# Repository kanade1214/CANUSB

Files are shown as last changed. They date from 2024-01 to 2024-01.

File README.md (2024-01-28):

# CANUSB 

created by kanade @kanade___1214

CAN通信とUSBのブリッジ基板です。  
高専ロボコン2023用に作成したものを配布用に安価に、誰でも使えるようにしました。  
作成、使用は自由ですが、kanadeに一声DMしていただけると喜びます。つながりを増やしたいので  

2024/1/28現在テスト期間につきプログラムの動作確認ができていない状況です。  
テスト期間が終わるまで少々お待ちください。  
代わりにPCでmidiを再生するとCANのパケットにするプログラムを入れてあります。

プログラムを書き込む前にプログラムの中にあるUSBのPIDをご自身のものに書き換えてください。  
~そのままで動く！わからない人はそのままで！~  

ROS2パッケージの説明を下に記述します。
(ROS2協力：@Pine_Pino_Pine)

# ROS2 can_communication

文責：Pine

## 前提

- ROS 2 Humble と Ubuntu 22.04 で動作確認済み
- Pythonライブラリpyserialを使用
    
    ```bash
    $ pip install pyserial
    ```
    
- カスタムメッセージ`CanMsg.msg`を使用
    
    ```cpp
    bool channel
    bool frametype
    uint32 id
    byte dlc
    byte[<=8] data
    ```
    
- kanade設計のCAN-USB基板を使用

## トピック

### publish

USB-CAN基板から受け取ったCANパケットをCanMsg型topic`/can_rx`としてpublishする

### subscribe

subscribeしたCanMsg型topic`/can_tx`をUSB-CAN基板にserialとして流す

## 通信仕様

### Serial

|  | 1 byte目 | 2 byte目 | 3 byte目 | 4~6 byte目 | 7 byte目 | 8~15 byte目 | 最後 |
| --- | --- | --- | --- | --- | --- | --- | --- |
| 目的 | メッセージ開始 | チャンネル | フレームタイプ | ID | DLC | データ | メッセージ終了 |
| 形式 | 0x02 | ASCIIコード | ASCIIコード | ASCIIコード | ASCIIコード |  | 0x03 |
| 備考 | tx時のみ　rxでは無し | ‘0’ or ‘1’ | ‘0’ or ‘1’ | 16進数 3桁 | ’1’ ~ ‘8’ | DLCに対応した長さ | tx時のみ　rxでは無し |

フレームタイプが1（リモートフレーム）のときはDLCに関わらずdataは無効（rx時は無視され、tx時は空）

### CanMsg

|  | 目的 | 型 (ROS) | 型 (Python) | 型 (C++) | 形式 |
| --- | --- | --- | --- | --- | --- |
| channel | 使用するCAN Busのチャンネル | bool | bool | bool | false: ch0　true: ch1 |
| frametype | データフレームとリモートフレームの選択 | bool | bool | bool | false: データフレーム　true: リモートフレーム |
| id | CANデバイスのID | uint32 | int | uint32_t | 非負整数（例：0x201なら513） |
| dlc | データのbyte長 | byte | bytes | uint8_t | ASCIIコード 1文字 |
| data | データ | byte配列 | bytesリスト | uint8_t配列 | 各デバイスの仕様による |

## Pythonでの使用例

### TX

```python
import rclpy
from rclpy.node import Node
from custom_messages.msg import CanMsg

class publisher(Node) :
    def __init__(self) :
        super().__init__('publisher')
        
        self.pub = self.create_publisher(CanMsg, '/can_tx', 1)
        
        # 1秒周期で整数値とテキストを送信させる
        self.create_timer(1, self.publish_integer)
        self.create_timer(1, self.publish_text)
    
    def publish_integer(self) :
        # 送信する数値（符号なし8bit整数型の範囲内）
        num = 120
        
        msg = CanMsg()
        msg.channel = False
        msg.frametype = False
        msg.id = 0x101
        msg.dlc = b'1'                  # int型でもstr型でもなくbytes型
        msg.data = [str(num).encode()]  # 要素が一つでもリストにする
        
        self.pub.publish(msg)
        
    def publish_text(self) :
        # 送信するテキスト（str型ではなくbytes型）
        txt = b'Hello'
        
        msg = CanMsg()
        msg.channel = False
        msg.frametype = False
        msg.id = 0x102
        msg.dlc = str(len(txt)).encode()      # DLCを自動設定
        msg.data = [bytes([c]) for c in txt]  # これが少し複雑なので注意
        
        self.pub.publish(msg)

def main() :
    rclpy.init()
    node = publisher()
    
    try :
        rclpy.spin(node)
    except Exception :
        node.destroy_node()
        rclpy.shutdown()

if __name__ == '__main__' :
    main()
```

### RX

```python
import rclpy
from rclpy.node import Node
from custom_messages.msg import CanMsg

class subscriber(Node) :
    def __init__(self) :
        super().__init__('subscriber')
        
        self.data1 = 0
        self.data2 = 0
        
        self.sub = self.create_subscription(CanMsg, '/can_rx', self.callback, 10)
    
    def callback(self, msg) :
　　　　　# idによって処理を分岐
        if msg.id == 0x201 :
            # 整数値が1byteで送信される場合
            self.data1 = int.from_bytes(msg.data[0], 'big')
        elif msg.id == 0x202 :
            # 整数値がASCIIコード列として送信される場合
            self.data2 = int(b''.join(msg.data))

def main() :
    rclpy.init()
    node = subscriber()
    
    try :
        rclpy.spin(node)
    except Exception :
        node.destroy_node()
        rclpy.shutdown()

if __name__ == '__main__' :
    main()
```

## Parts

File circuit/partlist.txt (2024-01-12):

Partlist

Exported from untitled.brd at 2024/01/12 18:44

EAGLE Version 9.6.2 Copyright (c) 1988-2020 Autodesk, Inc.

Assembly variant: 

Part     Value                Package            Library                    Position (mm)         Orientation

C1       10u                  C1608              Robocon-RLC                (39 27)               MR270
C2       0.1u                 C1608              Robocon-RLC                (18 27)               MR270
C3       0.1u                 C1608              Robocon-RLC                (18 19)               MR270
C4       0.1u                 C1608              Robocon-RLC                (34 13)               MR180
C5       0.1u                 C1608              Robocon-RLC                (29.35 13)            MR180
C6       100u                 C3216              Robocon-RLC                (16.15 10.4)          MR270
C7       100u                 C3216              Robocon-RLC                (26.15 10.4)          MR270
C8       0.1u                 C:1                Robocon-RLC                (36.5 42)             R0
C9       0.1u                 C:1                Robocon-RLC                (20.5 42)             R180
C10      0.1u                 C1608              Robocon-RLC                (39 23)               MR270
C11      0.1u                 C1608              Robocon-RLC                (18 23)               MR270
C12      0.1u                 C1608              Robocon-RLC                (26.6 34)             MR0
C13      0.1u                 C1608              Robocon-RLC                (13.95 10.95)         MR270
C15      0.1u                 C1608              Robocon-RLC                (69 17.3)             MR90
C16      0.1u                 C1608              Robocon-RLC                (68.75 37.3)          MR90
IC1      MCP2562FDT-E_SN      SOIC127P600X175-8N MCP2562FDT-E_SN            (75 17.5)             MR180
IC2      NJM2845DL1           TO252              Robocon-Regulator          (21 7)                MR180
IC3      DSPIC33EP512MU810QFP TQFP100_0.5        Robocon-PICMicroController (28.5 23.5)           MR90
IC4      MCP2562FDT-E_SN      SOIC127P600X175-8N MCP2562FDT-E_SN            (75 37.5)             MR180
J1       GSB1C41110SSHR       GSB1C41110SSHR     GSB1C41110SSHR             (5 27.5)              R270
J2       PA4                  PA4                Robocon-Connector          (87 34.5)             R270
J3       PA4                  PA4                Robocon-Connector          (87 14.5)             R270
JP3                           1X05/90            Robocon-Pin_Header         (42.52 53.44)         R0
LED1     OSWT1608             LEDC1608X70N       OSWT1608                   (42 9)                R90
LED2     OSWT1608             LEDC1608X70N       OSWT1608                   (47 9)                R90
LED3     OSWT1608             LEDC1608X70N       OSWT1608                   (52 9)                R90
LED4     OSWT1608             LEDC1608X70N       OSWT1608                   (57 9)                R90
Q2       12M                  QS                 Robocon-Other              (28.5 42)             R0
R1       5.1k                 C1608              Robocon-RLC                (13 31)               MR270
R2       5.1k                 C1608              Robocon-RLC                (13 24)               MR270
R3       0                    C1608              Robocon-RLC                (77 29)               MR180
R4       120                  C1608              Robocon-RLC                (73 32)               MR180
R5       0                    C1608              Robocon-RLC                (77 32)               MR180
R6       0                    C1608              Robocon-RLC                (77 9)                MR180
R7       120                  C1608              Robocon-RLC                (73 12)               MR180
R8       100                  C1608              Robocon-RLC                (28.85 48.8)          MR90
R9       10k                  C1608              Robocon-RLC                (24.2 48.8)           MR90
R10      0                    C1608              Robocon-RLC                (77 12)               MR180
R11      300                  C1608              Robocon-RLC                (42 13)               MR90
R12      300                  C1608              Robocon-RLC                (47 13)               MR90
R13      300                  C1608              Robocon-RLC                (52 13)               MR90
R14      300                  C1608              Robocon-RLC                (57 13)               MR90
S1                            B3F-10XX           Robocon-Switches           (12 45.4)             R270
S2       SS-12D003G           SS-12D003G         Robocon-Switches           (7.75 11.8)           R180

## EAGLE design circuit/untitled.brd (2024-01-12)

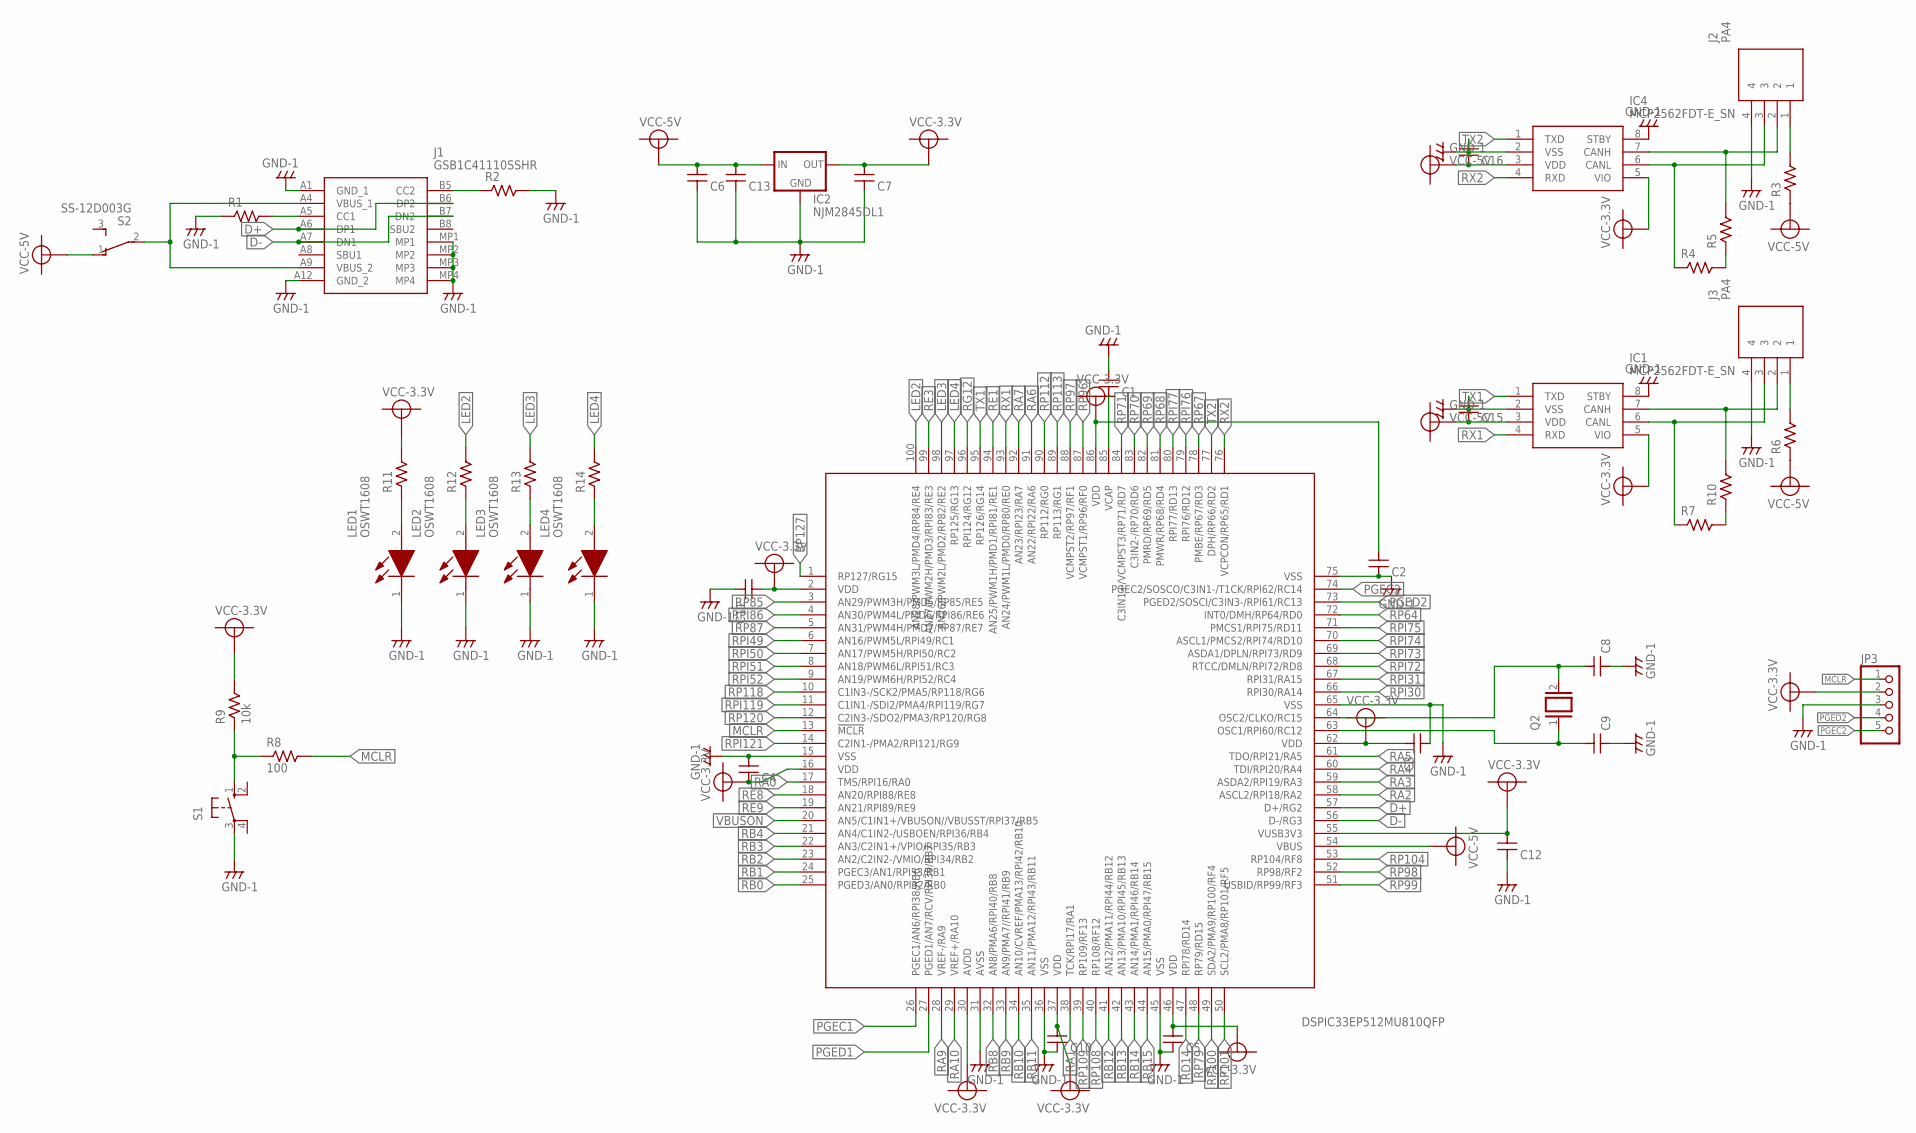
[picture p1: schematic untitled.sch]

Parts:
C1, C2, C3, C4, C5, C10, C11, C12, C13, C15, C16: CC1068; C1608
C6, C7: CC3216; C3216
C8, C9: CC2.54; C:1
IC1, IC4: MCP2562FDT-E_SN; SOIC127P600X175-8N
IC2: NJM2845DL1; TO252
IC3: DSPIC33EP512MU810QFP; TQFP100_0.5
J1: GSB1C41110SSHR
J2, J3: PA4
JP3: PINHD-1X5/90; 1X05/90
LED1, LED2, LED3, LED4: OSWT1608; LEDC1608X70N
Q2: XTAL/S; QS
R1, R2, R3, R4, R5, R6, R7, R10, R11, R12, R13, R14: R1/10W; C1608
R8: 100; C1608
R9: 10k; C1608
S1: 10-XX; B3F-10XX
S2: SS-12D003G

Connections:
+3.3V: C2.1, C3.2, C4.2, C5.1, C7.1, C10.1, C11.1, C12.1, IC1.5 (VIO), IC2.3 (OUT), IC3.2 (VDD), IC3.16 (VDD), IC3.30 (AVDD), IC3.37 (VDD), IC3.46 (VDD), IC3.55 (VUSB3V3), IC3.62 (VDD), IC3.86 (VDD), IC4.5 (VIO), JP3.2, R9.2, R11.2
+5V: C6.1, C13.1, C15.2, C16.2, IC1.3 (VDD), IC2.1 (IN), IC3.54 (VBUS), IC4.3 (VDD), R3.1, R6.1, S2.1 (O)
D+: IC3.57 (D+/RG2), J1.A6 (DP1), J1.B6 (DP2)
D-: IC3.56 (D-/RG3), J1.A7 (DN1), J1.B7 (DN2)
GND: C1.1, C2.2, C3.1, C4.1, C5.2, C6.2, C7.2, C8.P$2, C9.P$2, C10.2, C11.2, C12.2, C13.2, C15.1, C16.1, IC1.2 (VSS), IC1.8 (STBY), IC2.2 (GND), IC3.15 (VSS), IC3.31 (AVSS), IC3.36 (VSS), IC3.45 (VSS), IC3.65 (VSS), IC3.75 (VSS), IC4.2 (VSS), IC4.8 (STBY), J1.A1 (GND_1), J1.A12 (GND_2), J1.MP1, J1.MP2, J1.MP3, J1.MP4, J2.4, J3.4, JP3.3, LED1.1 (K), LED2.1 (K), LED3.1 (K), LED4.1 (K), R1.1, R2.2, S1.3
LED2: IC3.100 (AN28/PWM3L/PMD4/RP84/RE4), R12.2
LED3: IC3.98 (AN26/PWM2L/PMD2/RP82/RE2), R13.2
LED4: IC3.97 (RP125/RG13), R14.2
MCLR: IC3.13 (!MCLR), JP3.1, R8.2
unnamed: C9.P$1, IC3.63 (OSC1/RPI60/RC12), Q2.1
unnamed: C8.P$1, IC3.64 (OSC2/CLKO/RC15), Q2.2
unnamed: IC4.7 (CANH), J2.2, R5.2
unnamed: IC4.6 (CANL), J2.3, R4.1
unnamed: C1.2, IC3.85 (VCAP)
unnamed: J2.1, R3.2
unnamed: R4.2, R5.1
unnamed: J1.B5 (CC2), R2.1
unnamed: J1.A5 (CC1), R1.2
unnamed: R8.1, R9.1, S1.1 (S)
unnamed: J1.A4 (VBUS_1), J1.A9 (VBUS_2), S2.2
unnamed: IC1.7 (CANH), J3.2, R10.2
unnamed: IC1.6 (CANL), J3.3, R7.1
unnamed: J3.1, R6.2
unnamed: R7.2, R10.1
unnamed: LED1.2 (A), R11.1
unnamed: LED2.2 (A), R12.1
unnamed: LED3.2 (A), R13.1
unnamed: LED4.2 (A), R14.1
PGEC1: IC3.26 (PGEC1/AN6/RPI38/RB6)
PGEC2: IC3.74 (PGEC2/SOSCO/C3IN1-/T1CK/RPI62/RC14), JP3.5
PGED1: IC3.27 (PGED1/AN7/RCV/RPI39/RB7)
PGED2: IC3.73 (PGED2/SOSCI/C3IN3-/RPI61/RC13), JP3.4
RA0: IC3.17 (TMS/RPI16/RA0)
RA1: IC3.38 (TCK/RPI17/RA1)
RA2: IC3.58 (ASCL2/RPI18/RA2)
RA3: IC3.59 (ASDA2/RPI19/RA3)
RA4: IC3.60 (TDI/RPI20/RA4)
RA5: IC3.61 (TDO/RPI21/RA5)
RA6: IC3.91 (AN22/RPI22/RA6)
RA7: IC3.92 (AN23/RPI23/RA7)
RA9: IC3.28 (VREF-/RA9)
RA10: IC3.29 (VREF+/RA10)
RB0: IC3.25 (PGED3/AN0/RPI32/RB0)
RB1: IC3.24 (PGEC3/AN1/RPI33/RB1)
RB2: IC3.23 (AN2/C2IN2-/VMIO/RPI34/RB2)
RB3: IC3.22 (AN3/C2IN1+/VPIO/RPI35/RB3)
RB4: IC3.21 (AN4/C1IN2-/USBOEN/RPI36/RB4)
RB8: IC3.32 (AN8/PMA6/RPI40/RB8)
RB9: IC3.33 (AN9/PMA7//RPI41/RB9)
RB10: IC3.34 (AN10/CVREF/PMA13/RPI42/RB10)
RB11: IC3.35 (AN11/PMA12/RPI43/RB11)
RB12: IC3.41 (AN12/PMA11/RPI44/RB12)
RB13: IC3.42 (AN13/PMA10/RPI45/RB13)
RB14: IC3.43 (AN14/PMA1/RPI46/RB14)
RB15: IC3.44 (AN15/PMA0/RPI47/RB15)
RD14: IC3.47 (RPI78/RD14)
RE1: IC3.94 (AN25/PWM1H/PMD1/RPI81/RE1)
RE3: IC3.99 (AN27/PWM2H/PMD3/RPI83/RE3)
RE8: IC3.18 (AN20/RPI88/RE8)
RE9: IC3.19 (AN21/RPI89/RE9)
RG12: IC3.96 (RPI124/RG12)
RP64: IC3.72 (INT0/DMH/RP64/RD0)
RP67: IC3.78 (PMBE/RP67/RD3)
RP68: IC3.81 (PMWR/RP68/RD4)
RP69: IC3.82 (PMRD/RP69/RD5)
RP70: IC3.83 (C3IN2-/RP70/RD6)
RP71: IC3.84 (C3IN1+/VCMPST3/RP71/RD7)
RP79: IC3.48 (RP79/RD15)
RP85: IC3.3 (AN29/PWM3H/PMD5/RP85/RE5)
RP87: IC3.5 (AN31/PWM4H/PMD7/RP87/RE7)
RP96: IC3.87 (VCMPST1/RP96/RF0)
RP97: IC3.88 (VCMPST2/RP97/RF1)
RP98: IC3.52 (RP98/RF2)
RP99: IC3.51 (USBID/RP99/RF3)
RP100: IC3.49 (SDA2/PMA9/RP100/RF4)
RP101: IC3.50 (SCL2/PMA8/RP101/RF5)
RP104: IC3.53 (RP104/RF8)
RP108: IC3.40 (RP108/RF12)
RP109: IC3.39 (RP109/RF13)
RP112: IC3.90 (RP112/RG0)
RP113: IC3.89 (RP113/RG1)
RP118: IC3.10 (C1IN3-/SCK2/PMA5/RP118/RG6)
RP120: IC3.12 (C2IN3-/SDO2/PMA3/RP120/RG8)
RP127: IC3.1 (RP127/RG15)
RPI30: IC3.66 (RPI30/RA14)
RPI31: IC3.67 (RPI31/RA15)
RPI49: IC3.6 (AN16/PWM5L/RPI49/RC1)
RPI50: IC3.7 (AN17/PWM5H/RPI50/RC2)
RPI51: IC3.8 (AN18/PWM6L/RPI51/RC3)
RPI52: IC3.9 (AN19/PWM6H/RPI52/RC4)
RPI72: IC3.68 (RTCC/DMLN/RPI72/RD8)
RPI73: IC3.69 (ASDA1/DPLN/RPI73/RD9)
RPI74: IC3.70 (ASCL1/PMCS2/RPI74/RD10)
RPI75: IC3.71 (PMCS1/RPI75/RD11)
RPI76: IC3.79 (RPI76/RD12)
RPI77: IC3.80 (RPI77/RD13)
RPI86: IC3.4 (AN30/PWM4L/PMD6/RPI86/RE6)
RPI119: IC3.11 (C1IN1-/SDI2/PMA4/RPI119/RG7)
RPI121: IC3.14 (C2IN1-/PMA2/RPI121/RG9)
RX1: IC1.4 (RXD), IC3.93 (AN24/PWM1L/PMD0/RP80/RE0)
RX2: IC3.76 (VCPCON/RP65/RD1), IC4.4 (RXD)
TX1: IC1.1 (TXD), IC3.95 (RP126/RG14)
TX2: IC3.77 (DPH/RP66/RD2), IC4.1 (TXD)
VBUSON: IC3.20 (AN5/C1IN1+/VBUSON//VBUSST/RPI37/RB5)

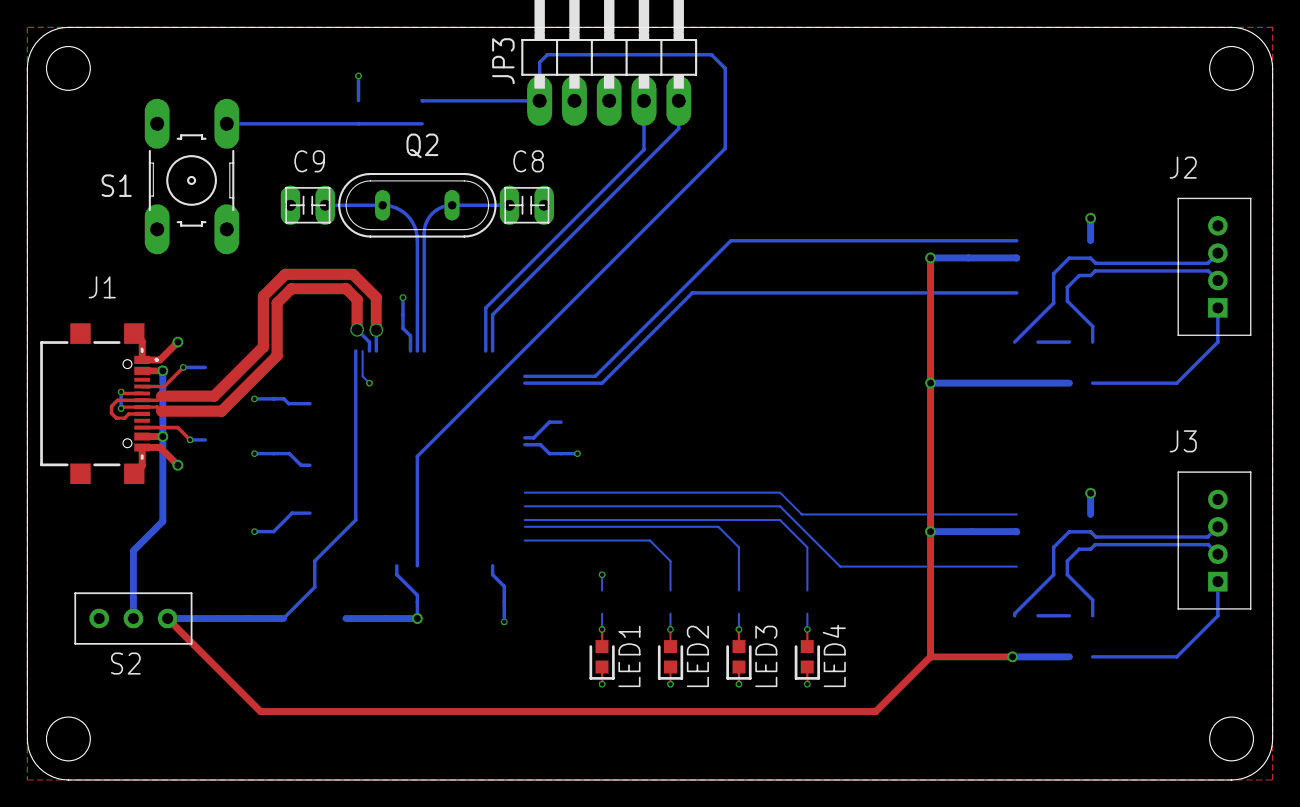
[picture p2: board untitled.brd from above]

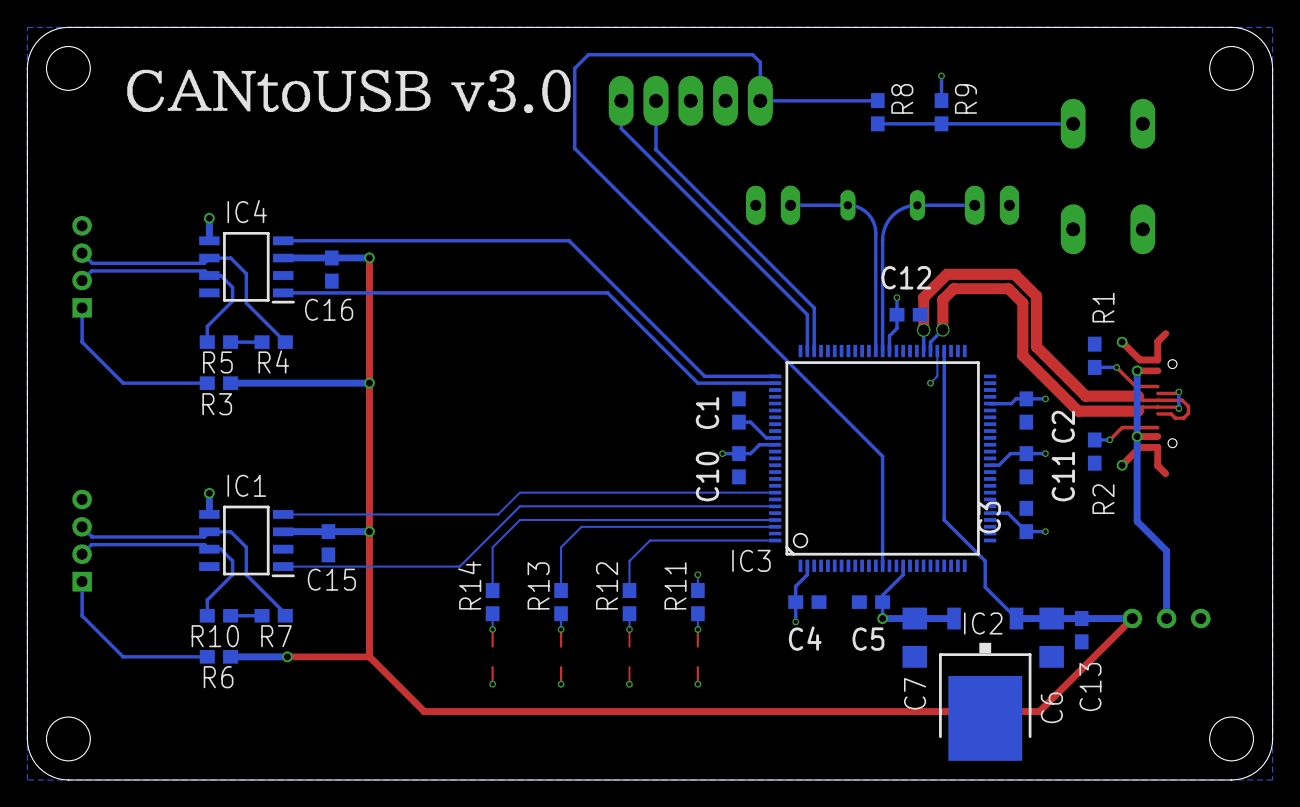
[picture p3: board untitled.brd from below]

Board: 2 copper layers, 91.0 x 55.0 mm, 44 parts (31 on the bottom side), 34 nets.

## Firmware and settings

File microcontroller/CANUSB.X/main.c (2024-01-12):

/**
  Generated main.c file from MPLAB Code Configurator

  @Company
    Microchip Technology Inc.

  @File Name
    main.c

  @Summary
    This is the generated main.c using PIC24 / dsPIC33 / PIC32MM MCUs.

  @Description
    This source file provides main entry point for system initialization and application code development.
    Generation Information :
        Product Revision  :  PIC24 / dsPIC33 / PIC32MM MCUs - 1.171.4
        Device            :  dsPIC33EP512MU810
    The generated drivers are tested against the following:
        Compiler          :  XC16 v2.10
        MPLAB 	          :  MPLAB X v6.05
*/

/*
    (c) 2020 Microchip Technology Inc. and its subsidiaries. You may use this
    software and any derivatives exclusively with Microchip products.

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
    IN NO EVENT WILL MICROCHIP BE LIABLE FOR ANY INDIRECT, SPECIAL, PUNITIVE,
    INCIDENTAL OR CONSEQUENTIAL LOSS, DAMAGE, COST OR EXPENSE OF ANY KIND
    WHATSOEVER RELATED TO THE SOFTWARE, HOWEVER CAUSED, EVEN IF MICROCHIP HAS
    BEEN ADVISED OF THE POSSIBILITY OR THE DAMAGES ARE FORESEEABLE. TO THE
    FULLEST EXTENT ALLOWED BY LAW, MICROCHIP'S TOTAL LIABILITY ON ALL CLAIMS IN
    ANY WAY RELATED TO THIS SOFTWARE WILL NOT EXCEED THE AMOUNT OF FEES, IF ANY,
    THAT YOU HAVE PAID DIRECTLY TO MICROCHIP FOR THIS SOFTWARE.

    MICROCHIP PROVIDES THIS SOFTWARE CONDITIONALLY UPON YOUR ACCEPTANCE OF THESE
    TERMS.
*/

/**
  Section: Included Files
*/
#include "mcc_generated_files/system.h"

/*
                         Main application
 */
int main(void)
{
    // initialize the device
    SYSTEM_Initialize();
    while (1)
    {
        // Add your application code
        MCC_USB_CDC_DemoTasks();
    }
    return 1; 
}
/**
 End of File
*/

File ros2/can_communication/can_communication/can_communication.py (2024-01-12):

import rclpy
from rclpy.node import Node
from custom_messages.msg import CanMsg
import serial
import time

class can_communication(Node) :
    def __init__(self) :
        super().__init__('can_communication')
        
        self.ser = serial.Serial()
        self.ser.port = '/dev/serial/by-id/usb-TMCIT_S_USBtoCAN.ver1-if00'
        self.ser.baudrate = 115200
        self.ser.parity = serial.PARITY_NONE
        self.ser.bytesize = serial.EIGHTBITS
        self.ser.stopbits = serial.STOPBITS_ONE
        self.ser.timeout = 0.1
        self.ser.write_timeout = 0.1
        self.ser.inter_byte_timeout = 0.1

        self.setup_serial() 
        
        self.pub = self.create_publisher(CanMsg, '/can_rx', 1)
        self.sub = self.create_subscription(CanMsg, '/can_tx', self.can_msg_callback, 20)

        self.create_timer(0.001, self.rxloop)

    def setup_serial(self) :
        if self.ser.is_open :
            self.ser.reset_input_buffer()
            self.ser.reset_output_buffer()
            self.ser.close()
        
        while not self.ser.is_open :
            try :
                self.ser.open()
            except Exception as e :
                self.get_logger().error('Setup Error')
                self.get_logger().error(str(e))
                time.sleep(1)

    def transmit_data(self, data) :
        tx = b'\x02' + data + b'\x03'
        # self.get_logger().info('tx: ' + str([*tx]))
        try :
            self.ser.write(tx)
            self.ser.flush()
        except Exception as e :
            self.get_logger().error('TX Error')
            self.get_logger().error(str(e))
            self.setup_serial()

    def receive_data(self) :
        rx = []
        try :
            while True :
                if (reading := self.ser.read()) != b'' :
                    rx += [reading]
                    # self.get_logger().info('RX: ' + str(reading))
                if len(rx) >= 6 and (int(rx[1]) or len(rx) == 6 + int(rx[5])) :
                    return b''.join(rx)
        except ValueError as e :
            self.get_logger().warn('RX Value Error: ' + str(rx))
        except Exception as e :
            self.get_logger().error('RX Error: ' + str(rx))
            self.get_logger().error(str(e))
            self.setup_serial()

    def rxloop(self) :
        if rx := self.receive_data() :
            if rx[2:4] == b'7f' :
                # self.get_logger().error('unchi')
                return
            # self.get_logger().info('rx_raw: ' + str([*rx]))
            self.publish_can_msg(rx)
    
    def publish_can_msg(self, rx) :
        try :
            msg = CanMsg()
            msg.channel = bool(int(chr(rx[0])))
            msg.frametype = bool(int(chr(rx[1])))
            msg.id = int(rx[2:5], 16)
            msg.dlc = bytes([rx[5]])
            msg.data = [bytes([b]) for b in rx[6:]] if not msg.frametype else b''
            # self.get_logger().info('rx: ' + str(msg))
            self.pub.publish(msg)
        except Exception as e:
            self.get_logger().error('Publish CAN Messages Error')
            self.get_logger().error(str(e))
    
    def can_msg_callback(self, msg) :
        # self.get_logger().info('sub: ' + str(msg))
        try :
            tx = str(int(msg.channel)).encode() + str(int(msg.frametype)).encode() + format(msg.id, '03x').encode() + str(int(msg.dlc)).encode() + b''.join(msg.data)
            self.transmit_data(tx)
        except Exception as e :
            self.get_logger().error('Subscribe CAN Messages Error')
            self.get_logger().error(str(e))

def main() :
    rclpy.init()
    node = can_communication()
    
    try :
        rclpy.spin(node)
    except KeyboardInterrupt :
        node.get_logger().error('Keyborad Interrupt')
        time.sleep(0.1)
    else :
        node.destroy_node()
        rclpy.shutdown()

if __name__ == '__main__' :
    main()
